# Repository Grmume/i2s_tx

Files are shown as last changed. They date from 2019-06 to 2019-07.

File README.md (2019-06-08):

# i2s_tx
Transceiver to transmit i2s over ethernet cable (4 channels per cable, >= Cat5).

The input of this board matches the pinout of the miniDsp Usbstreamer.
It can be used to transmit up to 8 channels of i2s audio over ethernet cable at upto 96 Kbit/s (hopefully). All channels share the same clocks.
Two of the RJ45 sockets have the same channels connected, to be able to have this PCB at the center of a setup and run one cable to the right side and one cable to the left side.

See the i2s_rxtx repository for information on how to receive the signals and convert them back to i2s.

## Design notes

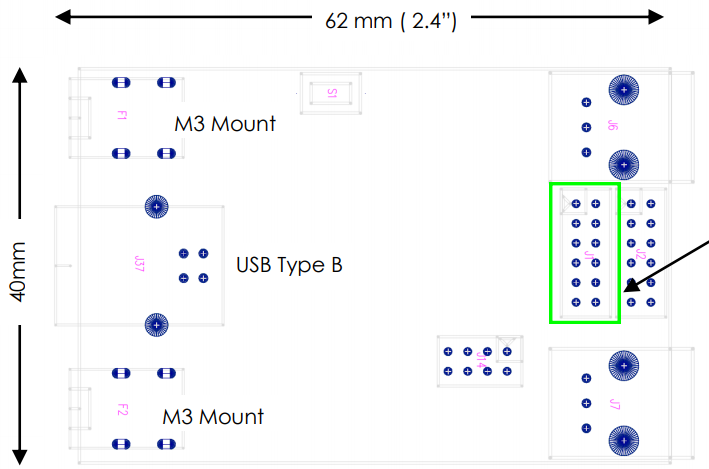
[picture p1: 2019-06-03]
2019-06-01 13_08_06-Product Brief - USBstreamer.png

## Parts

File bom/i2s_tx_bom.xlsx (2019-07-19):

Board | i2s_tx
BOM
References | Value | Footprint | Datasheet | Supplier1 Partnumber | Supplier2 Partnumber | Count | URL Reichelt | Unit Pr. Reichelt
> C1, C3, C4, C8 | 100nF | Capacitor_SMD:C_0805_2012Metric_Pad1.15x1.40mm_HandSolder |  |  |  | 4
> C2, C5, C6 | 10nF | Capacitor_SMD:C_0805_2012Metric_Pad1.15x1.40mm_HandSolder |  |  |  | 3
C7 | 10µF | Capacitor_SMD:CP_Elec_6.3x5.4 | ~ |  |  | 1
C9 | 2.2µF | Capacitor_SMD:C_0805_2012Metric_Pad1.15x1.40mm_HandSolder |  |  |  | 1
> IC1-IC3 | AM26C31 | Package_SO:SOIC-16_3.9x9.9mm_P1.27mm | http://www.ti.com.cn/cn/lit/ds/symlink/am26c31.pdf | 4975637 |  | 3
J1 | CONN_02x06 | Connector_PinHeader_2.00mm:PinHeader_2x06_P2.00mm_Vertical |  |  |  | 1
J2 | CONN_01x07 | Connector_PinHeader_2.00mm:PinHeader_1x07_P2.00mm_Vertical |  |  |  | 1
> J3-J5 | RJ45_Shielded | agg:RJ45_Weidmueller | ~ |  |  | 3
J6 | CONN_01x02 | Connector_PinHeader_2.00mm:PinHeader_1x02_P2.00mm_Vertical |  |  |  | 1

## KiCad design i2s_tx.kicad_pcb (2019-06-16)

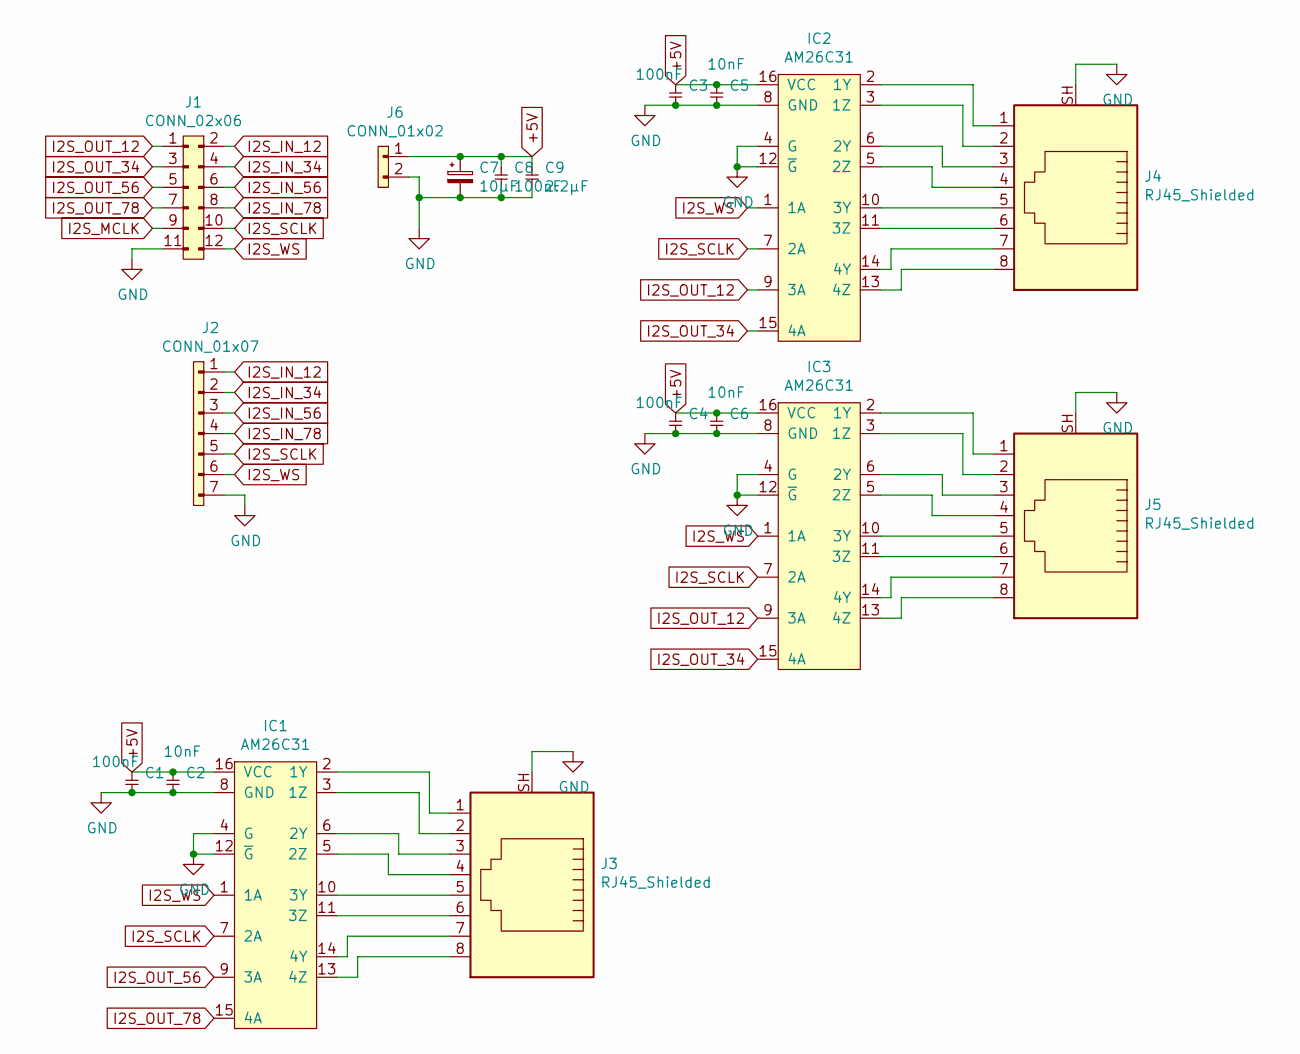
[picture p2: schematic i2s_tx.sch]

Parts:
C1, C3, C4, C8: 100nF; C_0805_2012Metric_Pad1.15x1.40mm_HandSolder
C2, C5, C6: 10nF; C_0805_2012Metric_Pad1.15x1.40mm_HandSolder
C7: 10µF; CP_Elec_6.3x5.4
C9: 2.2µF; C_0805_2012Metric_Pad1.15x1.40mm_HandSolder
IC1, IC2, IC3: AM26C31; SOIC-16_3.9x9.9mm_P1.27mm; Farnell 4975637
J1: CONN_02x06; PinHeader_2x06_P2.00mm_Vertical
J2: CONN_01x07; PinHeader_1x07_P2.00mm_Vertical
J3, J4, J5: RJ45_Shielded; RJ45_Weidmueller
J6: CONN_01x02; PinHeader_1x02_P2.00mm_Vertical

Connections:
+5V: C1.1, C2.1, C3.1, C4.1, C5.1, C6.1, C7.1, C8.1, C9.1, IC1.16 (VCC), IC2.16 (VCC), IC3.16 (VCC), J6.1
GND: C1.2, C2.2, C3.2, C4.2, C5.2, C6.2, C7.2, C8.2, C9.2, IC1.4 (G), IC1.8 (GND), IC1.12 (~G), IC2.4 (G), IC2.8 (GND), IC2.12 (~G), IC3.4 (G), IC3.8 (GND), IC3.12 (~G), J1.11, J2.7, J3.SH, J4.SH, J5.SH, J6.2
I2S_IN_12: J1.2, J2.1
I2S_IN_34: J1.4, J2.2
I2S_IN_56: J1.6, J2.3
I2S_IN_78: J1.8, J2.4
I2S_MCLK: J1.9
I2S_OUT_12: IC2.9 (3A), IC3.9 (3A), J1.1
I2S_OUT_34: IC2.15 (4A), IC3.15 (4A), J1.3
I2S_OUT_56: IC1.9 (3A), J1.5
I2S_OUT_78: IC1.15 (4A), J1.7
I2S_SCLK: IC1.7 (2A), IC2.7 (2A), IC3.7 (2A), J1.10, J2.5
I2S_WS: IC1.1 (1A), IC2.1 (1A), IC3.1 (1A), J1.12, J2.6
unnamed: IC1.2 (1Y), J3.1
unnamed: IC1.3 (1Z), J3.2
unnamed: IC1.5 (2Z), J3.4
unnamed: IC1.6 (2Y), J3.3
unnamed: IC1.10 (3Y), J3.5
unnamed: IC1.11 (3Z), J3.6
unnamed: IC1.13 (4Z), J3.8
unnamed: IC1.14 (4Y), J3.7
unnamed: IC2.2 (1Y), J4.1
unnamed: IC2.3 (1Z), J4.2
unnamed: IC2.5 (2Z), J4.4
unnamed: IC2.6 (2Y), J4.3
unnamed: IC2.10 (3Y), J4.5
unnamed: IC2.11 (3Z), J4.6
unnamed: IC2.13 (4Z), J4.8
unnamed: IC2.14 (4Y), J4.7
unnamed: IC3.2 (1Y), J5.1
unnamed: IC3.3 (1Z), J5.2
unnamed: IC3.5 (2Z), J5.4
unnamed: IC3.6 (2Y), J5.3
unnamed: IC3.10 (3Y), J5.5
unnamed: IC3.11 (3Z), J5.6
unnamed: IC3.13 (4Z), J5.8
unnamed: IC3.14 (4Y), J5.7

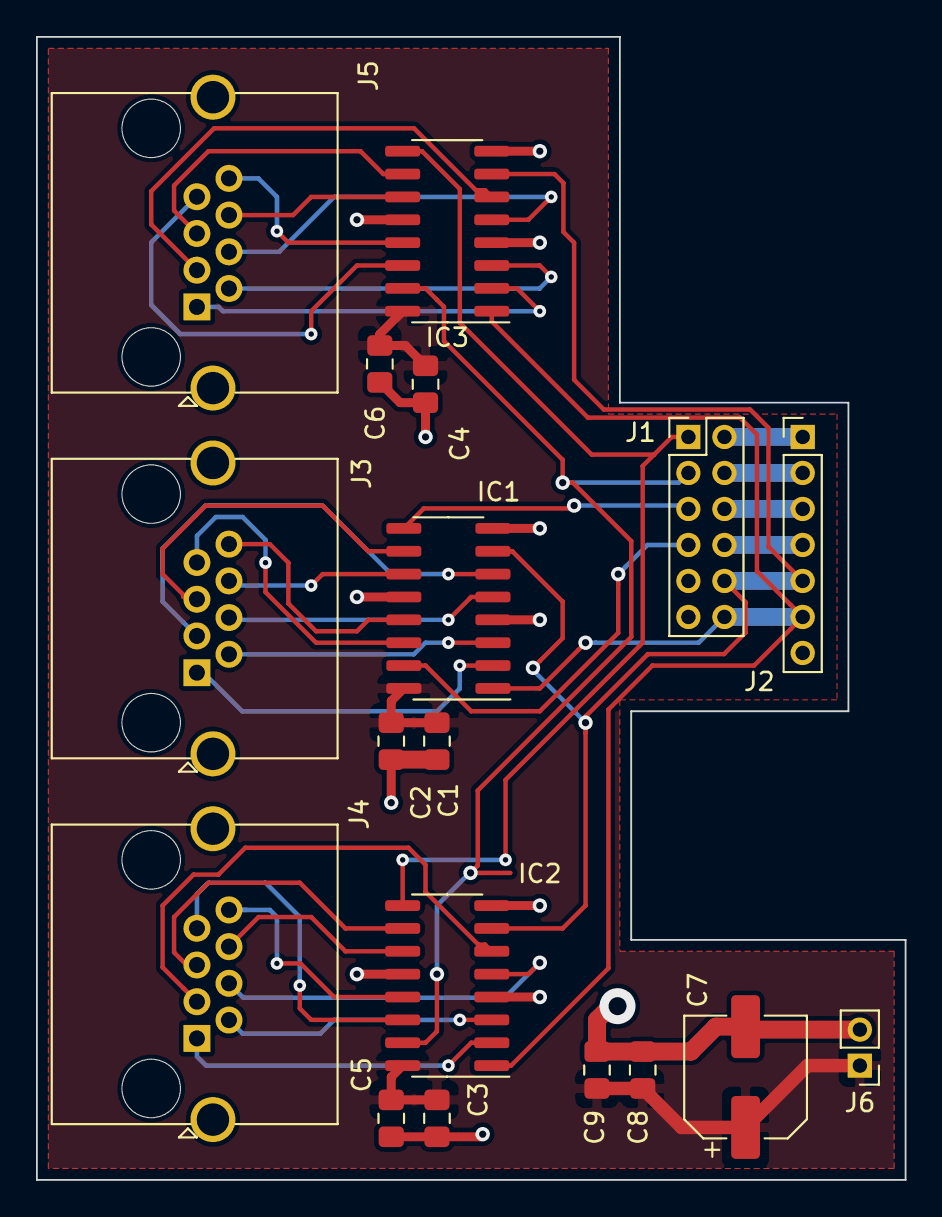
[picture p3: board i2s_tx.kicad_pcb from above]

Board: 2 copper layers, 48.3 x 63.5 mm, 18 parts (0 on the bottom side), 36 nets.

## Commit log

2019-06-03 -- added first version
    [i2s_tx.kicad_pcb, i2s_tx.sch]
2019-06-08 -- update
    [i2s_tx.kicad_pcb, i2s_tx.sch]
2019-06-16 --updated gerbers
    [i2s_tx-B_Cu.gbr, i2s_tx-B_Mask.gbr, i2s_tx-B_SilkS.gbr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]
2019-06-16 -- updated vias
    [i2s_tx-B_Cu.gbr, i2s_tx-B_Mask.gbr, i2s_tx-B_SilkS.gbr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]
2019-06-16 -- updated silkscreen
    [i2s_tx.kicad_pcb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]
2019-07-19 -- added bom
    [i2s_tx_bom.xlsx]
